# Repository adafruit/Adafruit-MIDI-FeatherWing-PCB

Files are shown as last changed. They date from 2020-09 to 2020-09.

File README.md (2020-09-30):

## Adafruit MIDI FeatherWing Kit PCB

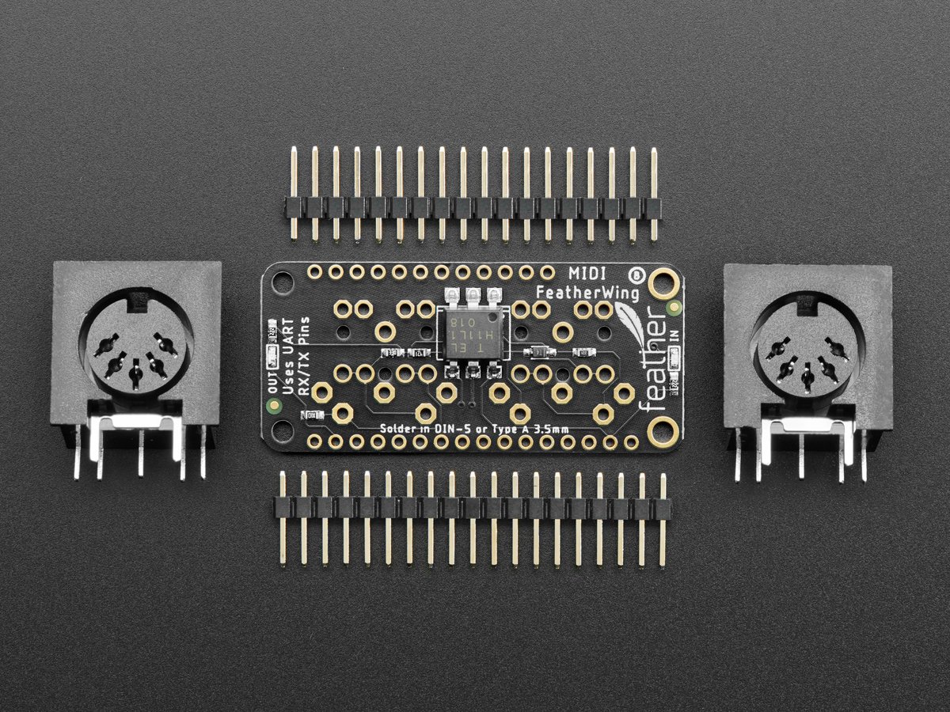
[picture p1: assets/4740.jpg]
<a href="http://www.adafruit.com/products/4740"><br/>
Click here to purchase one from the Adafruit shop</a>

PCB files for the Adafruit MIDI FeatherWing Kit.

Format is EagleCAD schematic and board layout
* https://www.adafruit.com/product/4740

### Description

Turn your Feather into a song-bird with this musically-enabled FeatherWing that adds MIDI input and output jacks to just about any Feather. You get both input and output DIN-5 MIDI jacks, a 3V optically isolator so you can interface with MIDI on 3.3V logic/power microcontrollers, and two blinky indicator LEDs underneath the jacks to help you know when data is sent and received.

For those who have moved from DIN-5 jacks to "TRS MIDI A" 3.5mm jacks, we provide spots to solder in 3.5mm stereo jacks (optional and not included by default)

We use the hardware serial pins RX and TX to send/receive data - you'll need to set these to 31250 baud in your programming language and then send/receive MIDI packet data. For example, here's how you would do it in Arduino or a full-featured library with helpers. Here's an example on using a UART for MIDI transport in CircuitPython.

Because we use the UART, this works with all Feathers except for those with USB-Serial converters that use the UART pins. Right now that means the ESP8266 Huzzah Feather, 328p Feather and nRF52 Feather don't work because they use the hardware UART for programming. Any other Feathers with native USB will work just fine.

Comes as a kit with an assembled PCB that has all the surface-mount components attached, loose headers, and two loose DIN-5 jacks. Some basic soldering is required to assemble the header and DIN jacks in place. If you're like to use 3.5mm jacks, you'll want to pick up some through-hole 3.5mm stereo jacks and solder those in, instead.

### License

Adafruit invests time and resources providing this open source design, please support Adafruit and open-source hardware by purchasing products from [Adafruit](https://www.adafruit.com)!

Designed by Limor Fried/Ladyada for Adafruit Industries.

Creative Commons Attribution/Share-Alike, all text above must be included in any redistribution.
See license.txt for additional details.

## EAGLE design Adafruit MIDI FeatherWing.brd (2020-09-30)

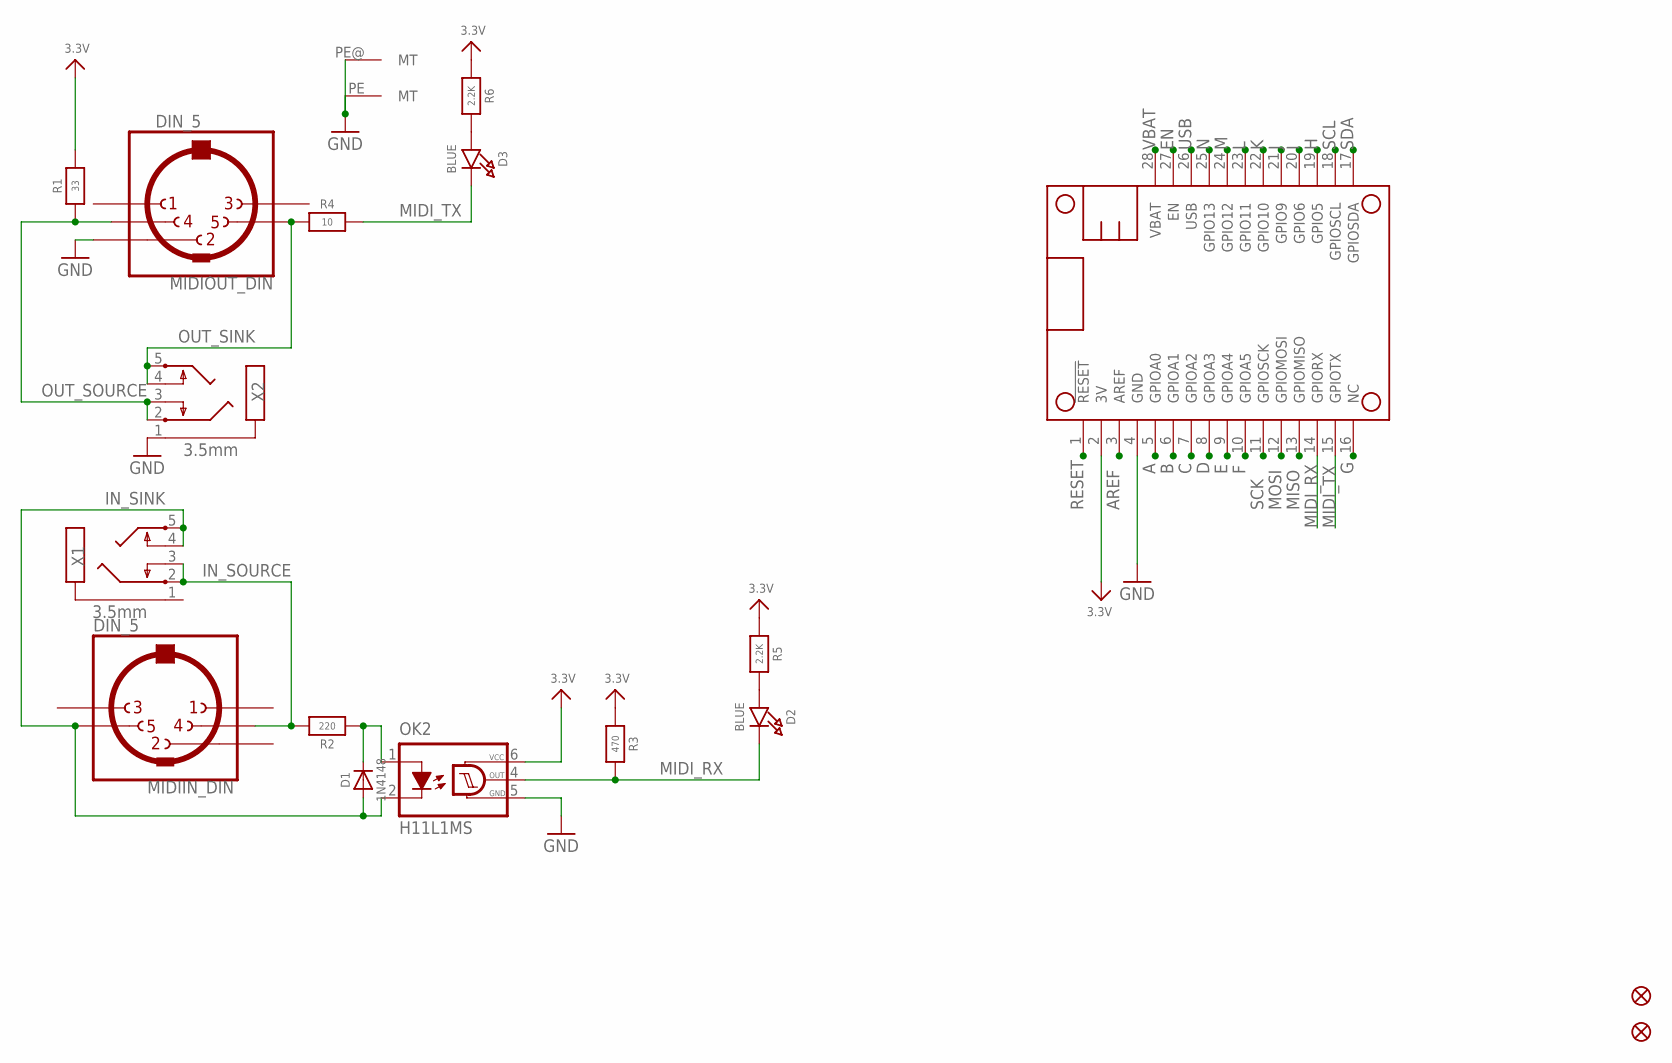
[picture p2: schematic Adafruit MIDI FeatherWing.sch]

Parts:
D1: 1N4148; SOD-323
D2, D3: BLUE; CHIPLED_0603
FID1, FID2: FIDUCIAL_1MM
MIDIIN: DIN_5; CP-2350
MIDIOUT: DIN_5; CP-2350
MS1: FEATHERWING_NODIM
OK2: H11L1MS; DIL6-SMD
R1: 33; 0603-NO
R2: 220; 0603-NO
R3: 470; 0603-NO
R4: 10; 0603-NO
R5, R6: 2.2K; 0603-NO
X1, X2: 3.5mm; STX3100

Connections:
3.3V: MS1.2 (3V), OK2.6 (VCC), R1.2, R3.1, R5.1, R6.1
A: MS1.5 (GPIOA0)
AREF: MS1.3 (AREF)
B: MS1.6 (GPIOA1)
C: MS1.7 (GPIOA2)
D: MS1.8 (GPIOA3)
E: MS1.9 (GPIOA4)
EN: MS1.27 (EN)
F: MS1.10 (GPIOA5)
G: MS1.16 (NC)
GND: MIDIOUT.2, MIDIOUT.PE (MT), MIDIOUT.PE@ (MT), MS1.4 (GND), OK2.5 (GND), X2.1
H: MS1.19 (GPIO5)
I: MS1.20 (GPIO6)
IN_SINK: D1.A, MIDIIN.5, OK2.2 (C), X1.4, X1.5
IN_SOURCE: MIDIIN.4, R2.2, X1.2, X1.3
J: MS1.21 (GPIO9)
K: MS1.22 (GPIO10)
L: MS1.23 (GPIO11)
M: MS1.24 (GPIO12)
MIDI_RX: D2.C, MS1.14 (GPIORX), OK2.4 (OUT), R3.2
MIDI_TX: D3.C, MS1.15 (GPIOTX), R4.2
MISO: MS1.13 (GPIOMISO)
MOSI: MS1.12 (GPIOMOSI)
N: MS1.25 (GPIO13)
unnamed: D2.A, R5.2
unnamed: D3.A, R6.2
unnamed: D1.C, OK2.1 (A), R2.1
OUT_SINK: MIDIOUT.5, R4.1, X2.4, X2.5
OUT_SOURCE: MIDIOUT.4, R1.1, X2.2, X2.3
RESET: MS1.1 (!RESET)
SCK: MS1.11 (GPIOSCK)
SCL: MS1.18 (GPIOSCL)
SDA: MS1.17 (GPIOSDA)
USB: MS1.26 (USB)
VBAT: MS1.28 (VBAT)

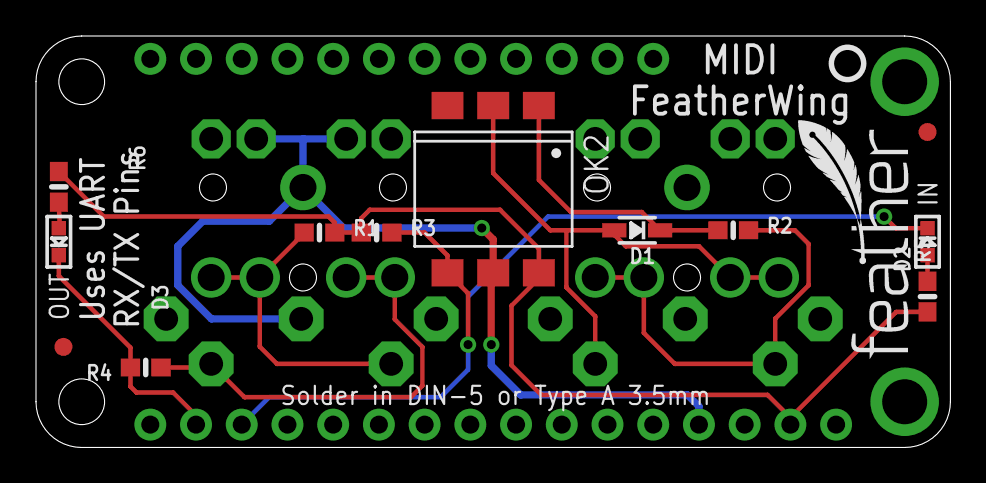
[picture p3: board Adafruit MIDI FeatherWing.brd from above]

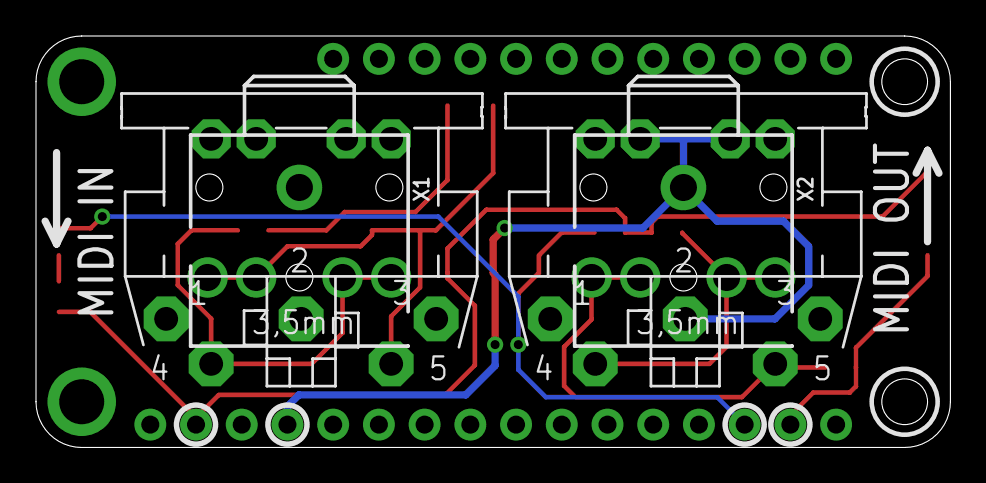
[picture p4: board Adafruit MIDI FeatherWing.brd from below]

Board: 2 copper layers, 50.8 x 22.9 mm, 19 parts (5 on the bottom side), 11 nets.

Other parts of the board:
U$8: PCBFEAT-REV-040
U$9: FEATHERLOGO_SMALL

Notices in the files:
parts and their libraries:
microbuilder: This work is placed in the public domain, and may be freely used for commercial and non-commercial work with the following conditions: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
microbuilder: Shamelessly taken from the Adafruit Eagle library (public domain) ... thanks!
